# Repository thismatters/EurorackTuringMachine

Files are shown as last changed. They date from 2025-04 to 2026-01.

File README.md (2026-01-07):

# Turing Machine

The Turing Machine is a hugely popular module which produces random sequences of configurable length which can be held constant, or allowed to change slowly over time. Think of it like a sample-hold for sequences.

The circuit here is based on the [Music Thing Modular Turing Machine](https://github.com/TomWhitwell/TuringMachine) with some minor tweaks. The changes I've made are thus:
* Added polarity protection so that a backward power header doesn't fry anything (twin series schotty diodes: BAT54SL),
* Full surface mount design on a single PCB,
* Simpler input power filtering,
* Expanded length choices to include 7, 9, 11, and 13 (in addition to the default 2, 3, 4, 5, 6, 8, 12, and 16).
* Schmitt trigger with hysteresis on clock input to handle input signals which aren't perfectly smooth (alleviating the tendancy of the Music Thing Modular circuit to double-clock)

This module should be a drop-in replacement for the Musing Thing Modular version with the same width and same basic panel layout. I've altered it somewhat to fit with the aesthetic and practices of my DIY build, however the pinouts for expansion modules adhere exactly to the original. This repo inherits the same license as the original Turing Machine: [CC-BY-SA](https://creativecommons.org/licenses/by-sa/3.0/)

The KiCAD project here uses the library/footprints [found in my companion repo](https://github.com/thismatters/EurorackKiCAD).

Note resistors R1 and R2 have been removed. You will not find them in the schematic or BOM.

## Width

10hp

## Inputs

Jacks:
- Clock (required input) -- Max clock rate: 1300Hz; higher frequencies will cause bit smearing.
- CV for setting "Change" rate

Knobs:
- Change rate
- Sequence length (12 position switch)
- Scale

Write switch for setting the current bit high or low.

## Outputs

Jacks:
- CV output of of sequence
- Whitenoise
- Pulse whenever the current bit is high

LEDs:
- 8x for the current binary representation of the output tone
- 1x for the pulse
- 1x for the clock input

## Vendors

There are part numbers in the [BOM](turing-machine.csv) for many of the parts (not for basic passives though) at the following vendors:

* [Mouser](https://www.mouser.com): Needs no introduction. Get your ICs from here (or [digikey](https://www.digikey.com)).
* [Tayda Electronics](https://www.taydaelectronics.com/): Good supplier for passive components; audio jacks, and potentiometers. Their audio jacks are slightly smaller than the thonkiconn from thonk.
* [Love My Switches](https://lovemyswitches.com/): Has [really good knobs](https://lovemyswitches.com/anodized-aluminum-knob-the-lo-fi-1-4-smooth-shaft-12-5mm-od/) to go on those potentiometers!
* [OSHPark](https://oshpark.com/): Fast and (relatively) cheap PCB manufacturer. ~[V1 board works great!](https://oshpark.com/shared_projects/wF94N3Eb)~ There is a problem with the randomness and change circuitry. Needs a new version.

## Changelog

### V1

* [x] Fixed pinout for DAC0800 which is different for SOIC than PDIP
* [x] Write switch rotated 180deg
* [x] Filters between shift registers removed (max clock rate confirmed at around 1330Hz (E6))
* [x] Schmitt trigger supplements op-amp in gate input stage
* [x] Flipped trimmer and added hole to front panel so that trimming can happen _in-situ_, added note to PCB about how the trimmer should be oriented.

### V1a

* [x] Corrected C12 to have value of 1nF
* [x] Added test points for:
  * LOOP_CTRL'
  * RAND'
* [x] Investigated noise interference
  * When several LEDs are lit the noise level drops dramatically
  * clipping the LEDS from the prototype PCB alleviated the problem.
  * It seems produent to run the LEDS from the buffer outputs (which drive the expanders), and to drive the buffers from an isolated power circuit.
* [x] tested the V1 circuit driving LEDs from expander to see if secondary power circuit is necessary
  * it is. Driving the LEDs via the buffer still brings the +12V rail from 11.45V to 11.15V
* [x] Tested if ferrite bead in place of 10ohm resistor for power conditioning corrects noise interference issue (seems to work fine)
* [x] Updated power circuit to use ferrite bead (81-BLM21SP700BH1D) instead of resistor to more closely match original design

#### V1 -> V1a refit
* Change capacitor C12 value to 1nF.
* Use ferrite bead in place of resistors R1 and R2. A suitable part with an matching footprint is available from Mouser.com: part number 81-BLM21SP700BH1D.

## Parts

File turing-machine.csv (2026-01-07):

# | Reference | Qty | Value | Footprint | DNP | Vendor | PartNum
1 | C1, C2 | 2 | 22u 50V | Capacitor_THT:CP_Radial_D5.0mm_P2.50mm
2 | C3, C4, C11, C13, C19, C20, C21, C22, C23, C24, C25 | 11 | 100n | Capacitor_SMD:C_0805_2012Metric
3 | C5 | 1 | 10n | Capacitor_SMD:C_0805_2012Metric
4 | C6, C9, C12 | 3 | 1n | Capacitor_SMD:C_0805_2012Metric
5 | C7, C8, C10 | 3 | 470n box | Capacitor_THT:C_Rect_L7.2mm_W4.5mm_P5.00mm_FKS2_FKP2_MKS2_MKP2
6 | D1, D2 | 2 | BAT54S | Package_TO_SOT_SMD:SOT-23 |  | Mouser | 863-BAT54SLT1G
7 | D3, D14 | 2 | 1N4148 | Diode_SMD:D_SOD-323_HandSoldering
8 | D4, D5, D6, D7, D8, D9, D10, D11, D12, D13 | 10 | LED_GREEN | LED_THT:LED_D3.0mm
9 | FB1, FB2 | 2 | 70 Ohm | Inductor_SMD:L_0805_2012Metric |  | Mouser | 81-BLM21SP700BH1D
10 | J1 | 1 | Conn_02x05_Odd_Even | Eurorack:PinHeader_2x05_P2.54mm_Vertical |  | Tayda | A-2939
11 | J2 | 1 | cv | Eurorack:AudioJack2_Tayda_A-2566 |  | Tayda | A-2566
12 | J3 | 1 | clock | Eurorack:AudioJack2_Tayda_A-2566 |  | Tayda | A-2566
13 | J4 | 1 | out | Eurorack:AudioJack2_Tayda_A-2566 |  | Tayda | A-2566
14 | J5 | 1 | noise | Eurorack:AudioJack2_Tayda_A-2566 |  | Tayda | A-2566
15 | J6, J7 | 2 | Conn_02x08_Odd_Even | Eurorack:PinHeader_2x08_P2.54mm_Vertical |  | Tayda | A-2956
16 | J8 | 1 | pulse | Eurorack:AudioJack2_Tayda_A-2566 |  | Tayda | A-2566
17 | Q1 | 1 | BC547 | Package_TO_SOT_THT:TO-92_Inline_Wide |  | Mouser | 637-BC547C
18 | Q2 | 1 | BCM847 | Package_SO:TSOP-6_1.65x3.05mm_P0.95mm |  | Mouser | 771-BCM847DS135
19 | R3, R4, R10, R18, R25, R26, R27, R34 | 8 | 10K | Resistor_SMD:R_0805_2012Metric
20 | R5, R7, R11, R17, R21, R29 | 6 | 100K | Resistor_SMD:R_0805_2012Metric
21 | R6 | 1 | 51K | Resistor_SMD:R_0805_2012Metric
22 | R8 | 1 | 8.2K | Resistor_SMD:R_0805_2012Metric
23 | R9 | 1 | 470 | Resistor_SMD:R_0805_2012Metric
24 | R12 | 1 | 3.9K | Resistor_SMD:R_0805_2012Metric
25 | R13 | 1 | 5.1K | Resistor_SMD:R_0805_2012Metric
26 | R14 | 1 | 3.3K | Resistor_SMD:R_0805_2012Metric
27 | R15, R16 | 2 | 1.6K | Resistor_SMD:R_0805_2012Metric
28 | R19, R32 | 2 | 470K | Resistor_SMD:R_0805_2012Metric
29 | R20, R22, R24 | 3 | 1K | Resistor_SMD:R_0805_2012Metric
30 | R23, R33 | 2 | 2.2K | Resistor_SMD:R_0805_2012Metric
31 | R28 | 1 | 47K | Resistor_SMD:R_0805_2012Metric
32 | R30 | 1 | 68K | Resistor_SMD:R_0805_2012Metric
33 | R31 | 1 | 15K | Resistor_SMD:R_0805_2012Metric
34 | RN1 | 1 | 2.2K | Resistor_THT:R_Array_SIP9 |  | Mouser | 652-4609X-1LF-2.2K
35 | RV1, RV2 | 2 | B50K | Eurorack:Potentiometer_RV16AF-41-15R1
36 | RV3 | 1 | 5K | Potentiometer_THT:Potentiometer_Bourns_3296W_Vertical
37 | SW1 | 1 | SW_Rotary12 | Eurorack:Switch_Rotary_NKK_MRK_112 |  | Mouser | 633-MRK112-BA
38 | SW2 | 1 | SW_SPDT_MSM | Eurorack:Switch_SPDT_1M_Solder_Lug |  | Tayda | A-6099
39 | U1, U5, U14 | 3 | TL072 | Package_SO:SOIC-8_3.9x4.9mm_P1.27mm |  | Mouser | 595-TL072CDR
40 | U2 | 1 | DAC0800_SOIC | Package_SO:SOIC-16_3.9x9.9mm_P1.27mm |  | Mouser | 926-DAC0800LCMX/NOPB
41 | U3 | 1 | TL431DBZ | Package_TO_SOT_SMD:SOT-23 |  | Mouser | 595-TL431BCDBZTG4
42 | U4 | 1 | 4016 | Package_SO:TSSOP-14_4.4x5mm_P0.65mm |  | Mouser | 595-CD4016BPWR
43 | U6, U7 | 2 | 4015 | Package_SO:TSSOP-16_4.4x5mm_P0.65mm |  | Mouser | 595-CD4015BPWR
44 | U8, U11 | 2 | L78L09_SOT89 | Package_TO_SOT_SMD:SOT-89-3 |  | Mouser | 511-L78L09ACU
45 | U9, U10 | 2 | 4050 | Package_SO:TSSOP-16_4.4x5mm_P0.65mm |  | Mouser | 595-CD4050BPWR
46 | U12, U13 | 2 | 4081 | Package_SO:TSSOP-14_4.4x5mm_P0.65mm |  | Mouser | 595-CD4081BPWR

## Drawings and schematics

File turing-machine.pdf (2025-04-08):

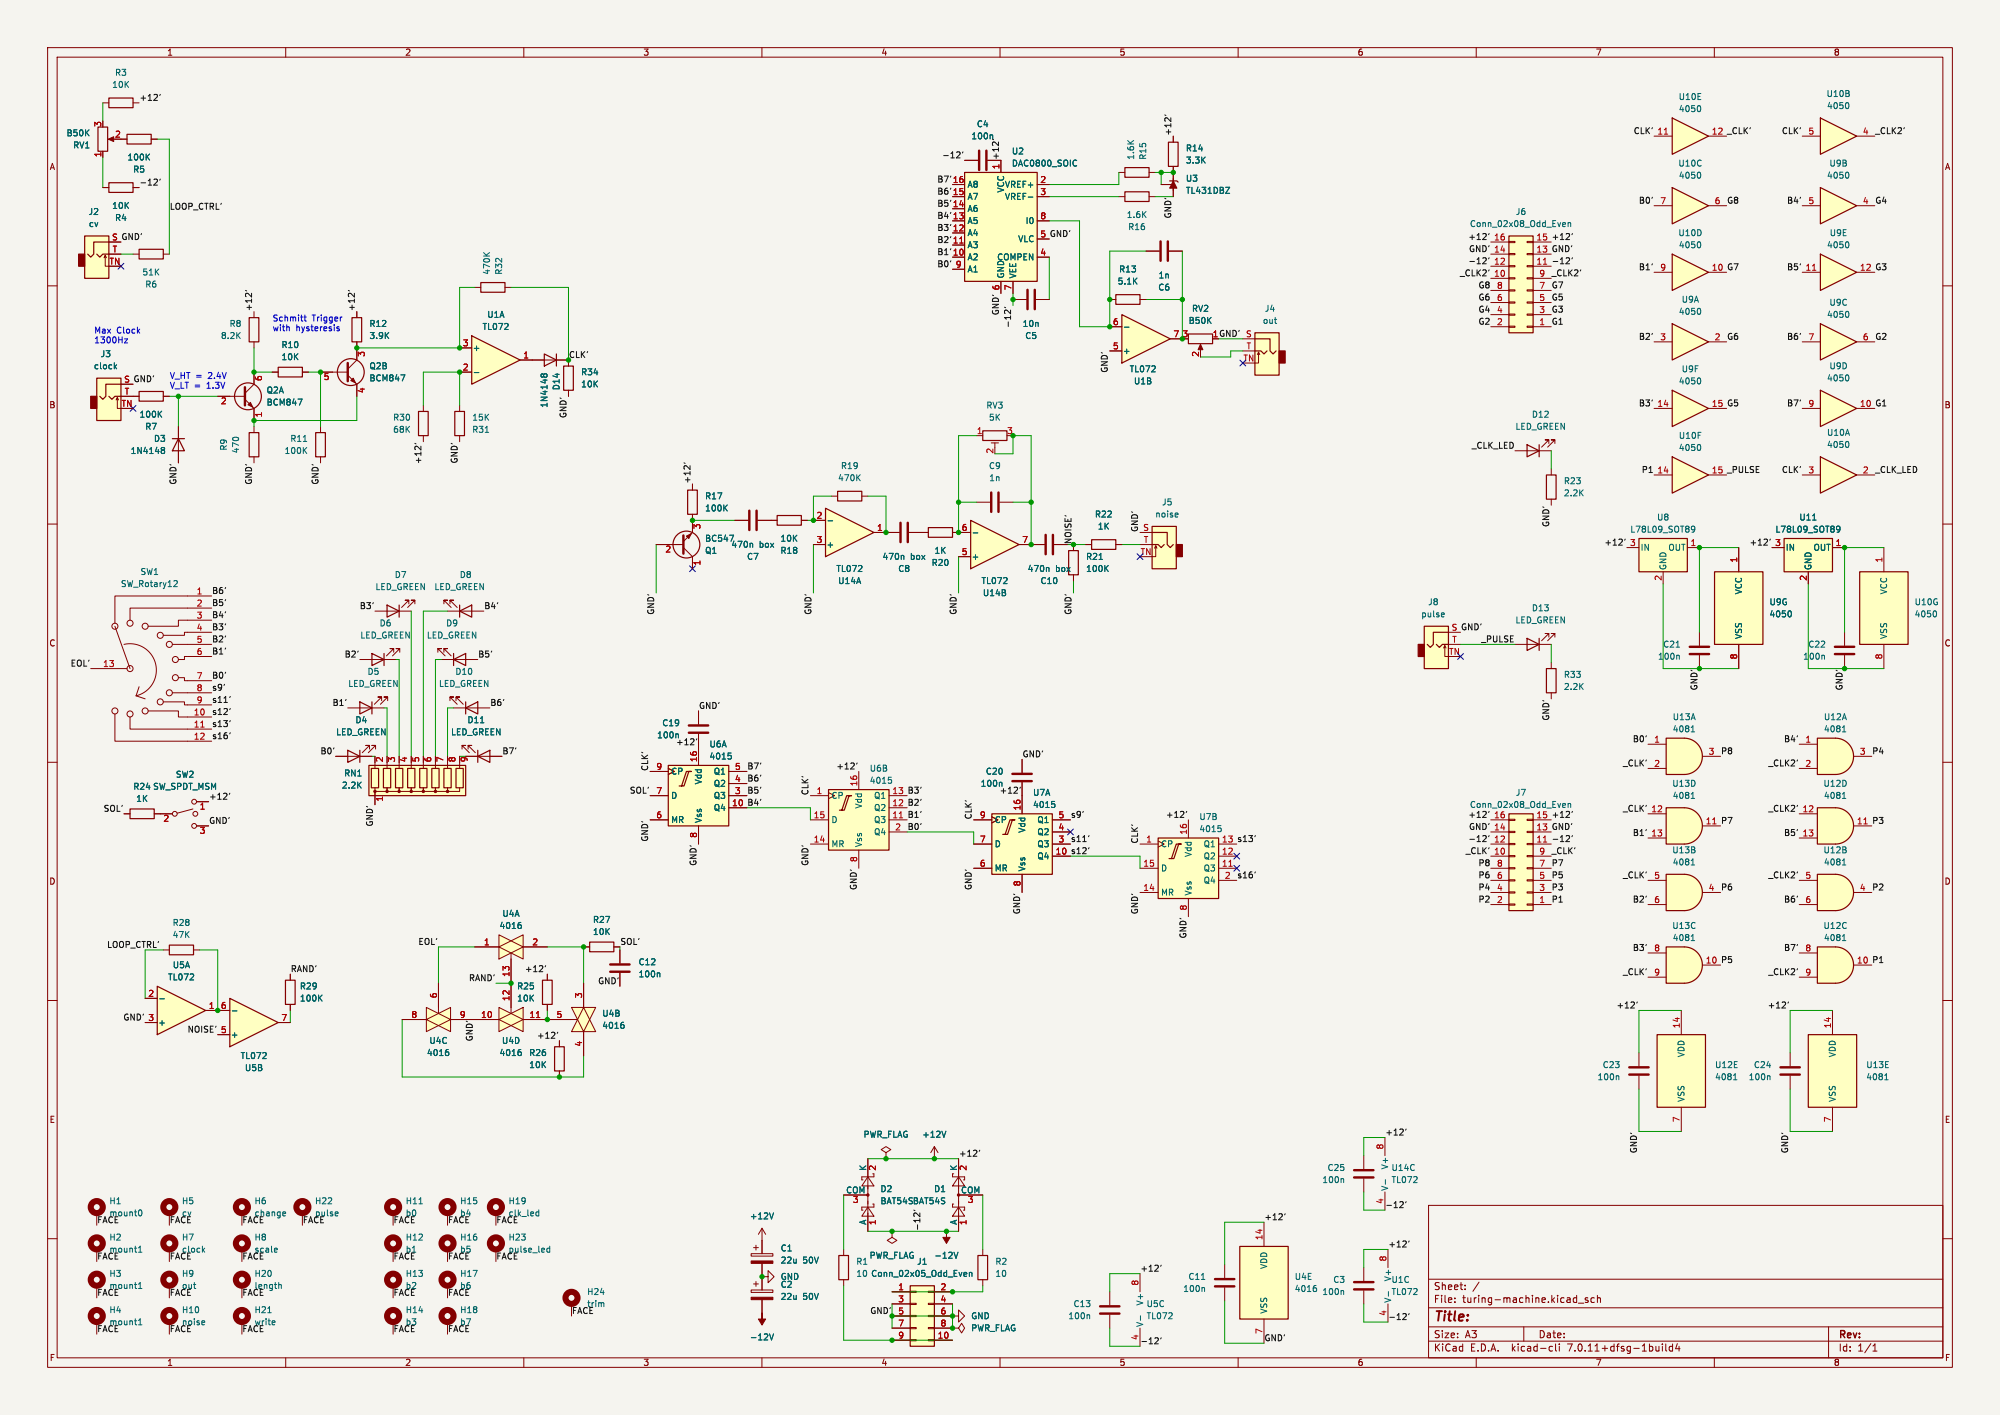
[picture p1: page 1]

1 A2 10 A3 11 A4 12 A5 13 A6 14 A7 15 A8 16 VREF+ 2 VREF- 3 COMPEN 4 VLC 5 GND

Id: 1/1 Title: File: turing-machine.kicad_sch Sheet: / +12V H8

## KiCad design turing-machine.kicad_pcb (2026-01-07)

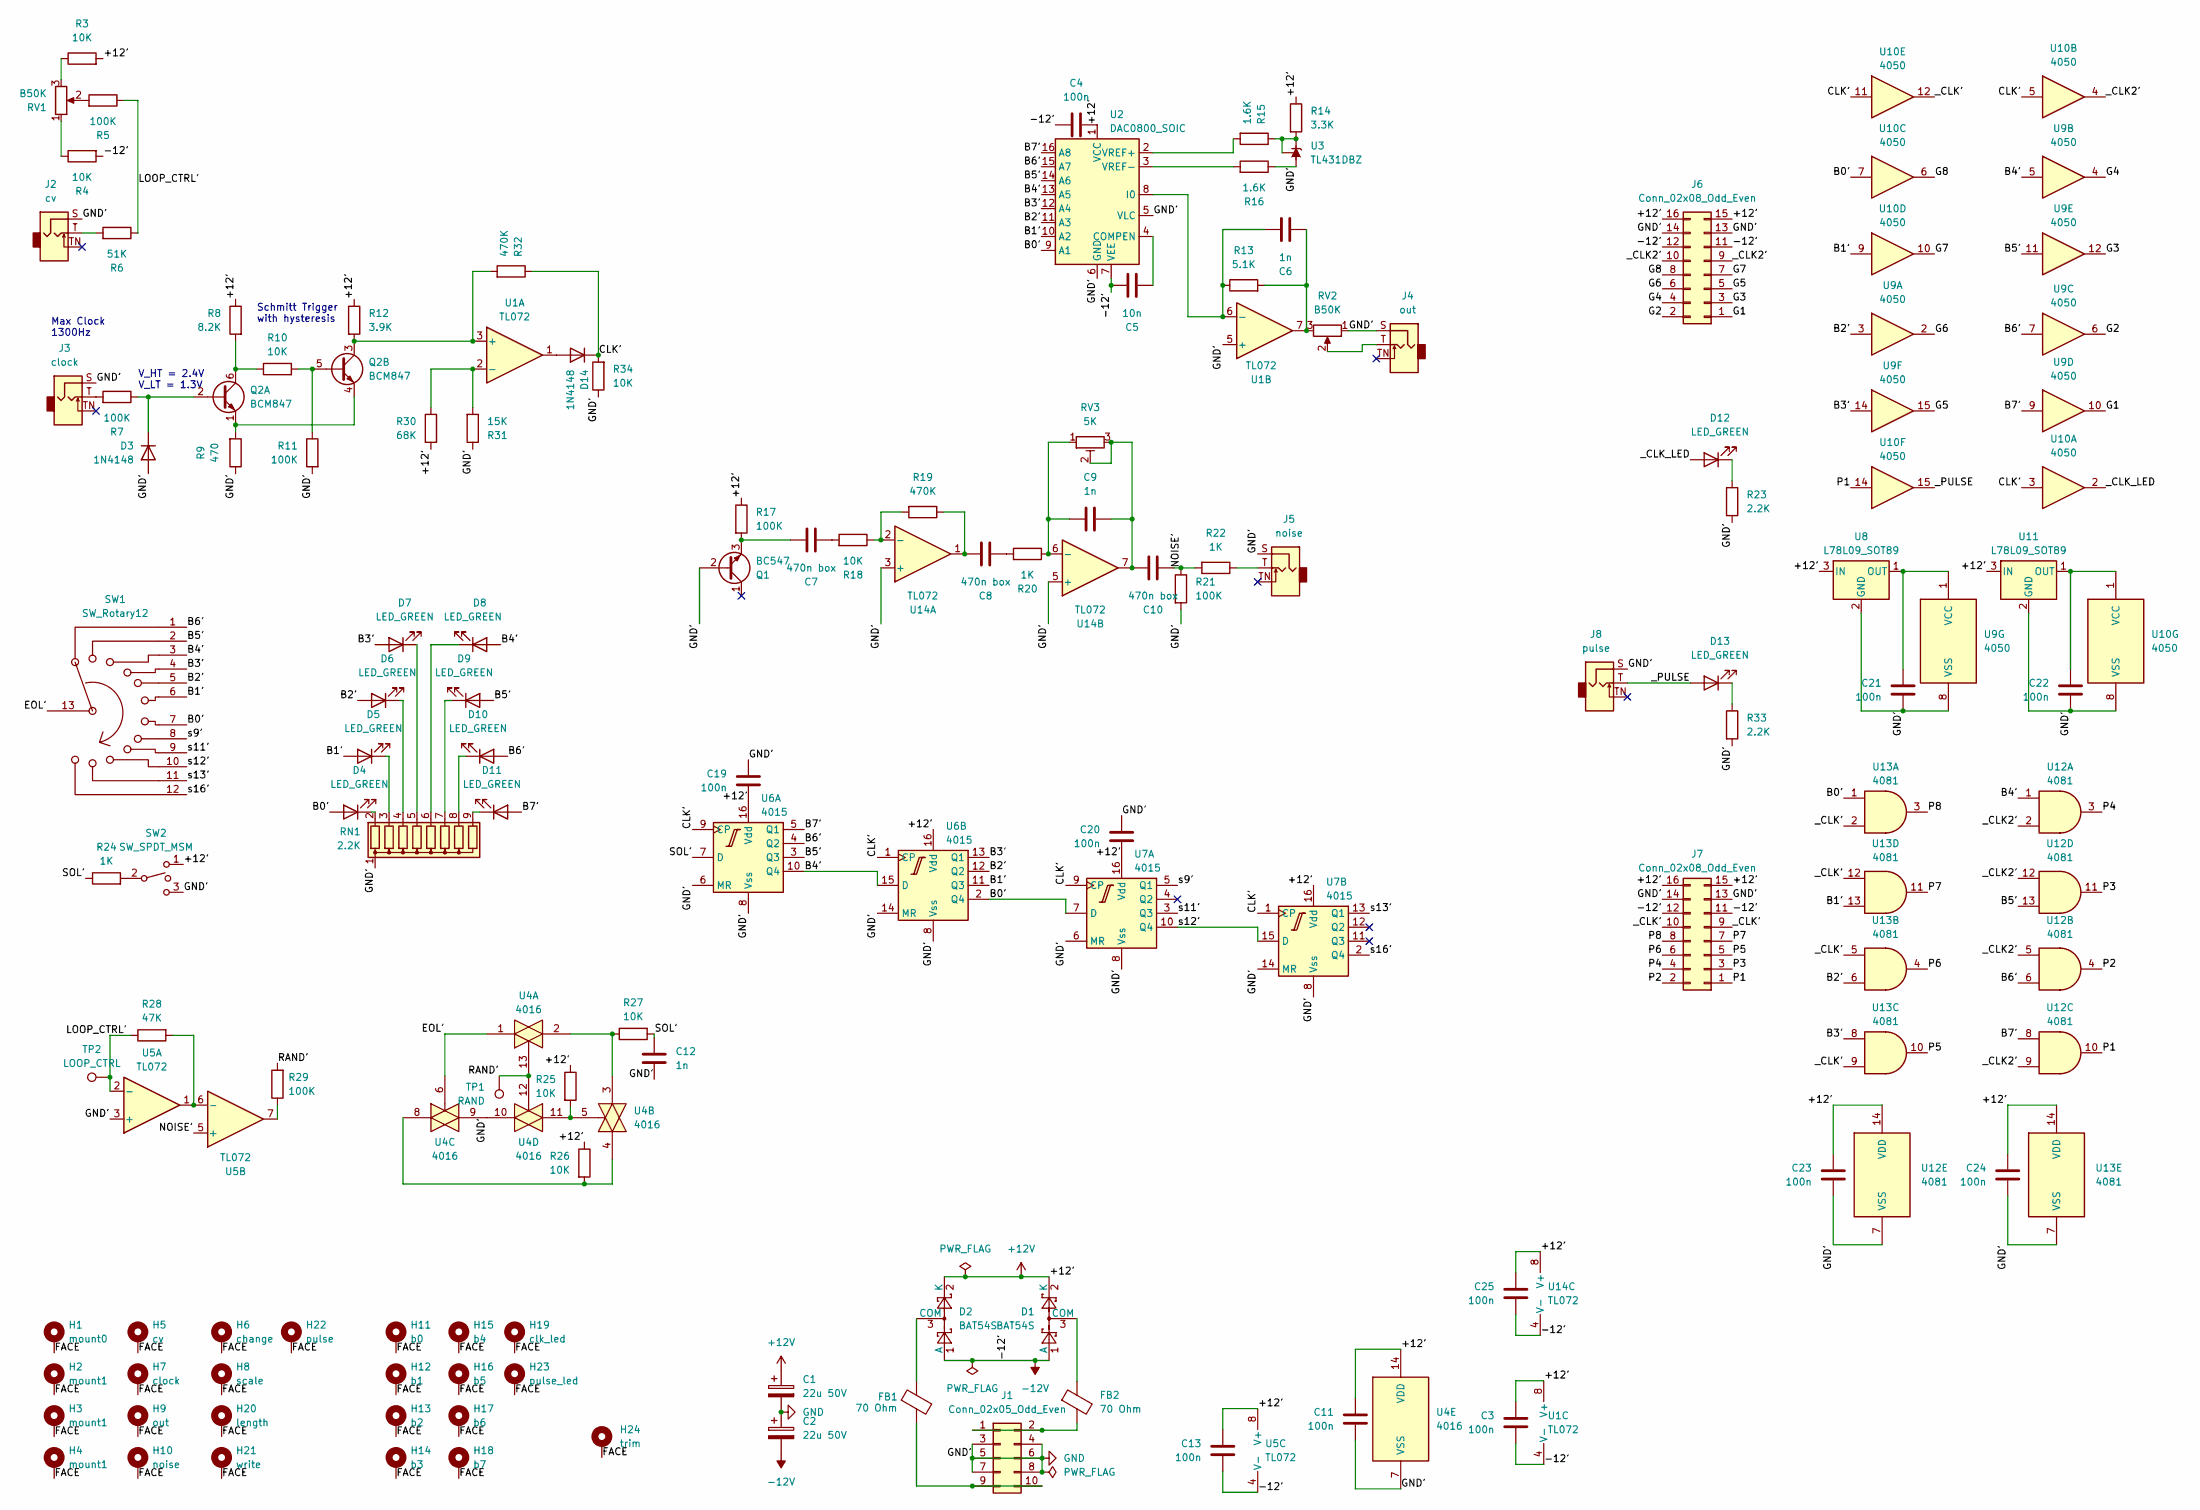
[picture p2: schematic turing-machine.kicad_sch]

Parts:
C1, C2: 22u 50V; CP_Radial_D5.0mm_P2.50mm
C3, C4, C11, C13, C19, C20, C21, C22, C23, C24, C25: 100n; C_0805_2012Metric
C5: 10n; C_0805_2012Metric
C6, C9, C12: 1n; C_0805_2012Metric
C7, C8, C10: 470n box; C_Rect_L7.2mm_W4.5mm_P5.00mm_FKS2_FKP2_MKS2_MKP2
D1, D2: BAT54S; SOT-23; PartNum 863-BAT54SLT1G
D3, D14: 1N4148; D_SOD-323_HandSoldering
D4, D5, D6, D7, D8, D9, D10, D11, D12, D13: LED_GREEN; LED_D3.0mm
FB1, FB2: 70 Ohm; L_0805_2012Metric; PartNum 81-BLM21SP700BH1D
H1: mount0; Mech-MountingHole
H2, H3, H4: mount1; Mech-MountingHole
H5: cv; Mech-AudioJack-Hole-Input-CV
H6: change; Mech-Potentiometer-Hole_level_180deg
H7: clock; Mech-AudioJack-Hole-Input-Clock
H8: scale; Mech-Potentiometer-Hole_level
H9: out; Mech-AudioJack-Hole-Output-CV
H10: noise; Mech-AudioJack-Hole-Output
H11: b0; Mech-LED-Hole-3mm
H12: b1; Mech-LED-Hole-3mm
H13: b2; Mech-LED-Hole-3mm
H14: b3; Mech-LED-Hole-3mm
H15: b4; Mech-LED-Hole-3mm
H16: b5; Mech-LED-Hole-3mm
H17: b6; Mech-LED-Hole-3mm
H18: b7; Mech-LED-Hole-3mm
H19: clk_led; Mech-LED-Hole-3mm
H20: length; Mech-MRK-Hole
H21: write; Mech-1M_Switch-Hole
H22: pulse; Mech-AudioJack-Hole-Output-Gate
H23: pulse_led; Mech-LED-Hole-3mm
H24: trim; Mech-LED-Hole-3mm
J1: Conn_02x05_Odd_Even; PinHeader_2x05_P2.54mm_Vertical; PartNum A-2939
J2: cv; AudioJack2_Tayda_A-2566; PartNum A-2566
J3: clock; AudioJack2_Tayda_A-2566; PartNum A-2566
J4: out; AudioJack2_Tayda_A-2566; PartNum A-2566
J5: noise; AudioJack2_Tayda_A-2566; PartNum A-2566
J6, J7: Conn_02x08_Odd_Even; PinHeader_2x08_P2.54mm_Vertical; PartNum A-2956
J8: pulse; AudioJack2_Tayda_A-2566; PartNum A-2566
Q1: BC547; TO-92_Inline_Wide; PartNum 637-BC547C
Q2: BCM847; TSOP-6_1.65x3.05mm_P0.95mm; PartNum 771-BCM847DS135
R3, R4, R10, R18, R25, R26, R27, R34: 10K; R_0805_2012Metric
R5, R7, R11, R17, R21, R29: 100K; R_0805_2012Metric
R6: 51K; R_0805_2012Metric
R8: 8.2K; R_0805_2012Metric
R9: 470; R_0805_2012Metric
R12: 3.9K; R_0805_2012Metric
R13: 5.1K; R_0805_2012Metric
R14: 3.3K; R_0805_2012Metric
R15, R16: 1.6K; R_0805_2012Metric
R19, R32: 470K; R_0805_2012Metric
R20, R22, R24: 1K; R_0805_2012Metric
R23, R33: 2.2K; R_0805_2012Metric
R28: 47K; R_0805_2012Metric
R30: 68K; R_0805_2012Metric
R31: 15K; R_0805_2012Metric
RN1: 2.2K; R_Array_SIP9; PartNum 652-4609X-1LF-2.2K
RV1, RV2: B50K; Potentiometer_RV16AF-41-15R1
RV3: 5K; Potentiometer_Bourns_3296W_Vertical
SW1: SW_Rotary12; Switch_Rotary_NKK_MRK_112; PartNum 633-MRK112-BA
SW2: SW_SPDT_MSM; Switch_SPDT_1M_Solder_Lug; PartNum A-6099
TP1: RAND; TestPoint_Plated_Hole_D2.0mm
TP2: LOOP_CTRL; TestPoint_Plated_Hole_D2.0mm
U1, U5, U14: TL072; SOIC-8_3.9x4.9mm_P1.27mm; PartNum 595-TL072CDR
U2: DAC0800_SOIC; SOIC-16_3.9x9.9mm_P1.27mm; PartNum 926-DAC0800LCMX/NOPB
U3: TL431DBZ; SOT-23; PartNum 595-TL431BCDBZTG4
U4: 4016; TSSOP-14_4.4x5mm_P0.65mm; PartNum 595-CD4016BPWR
U6, U7: 4015; TSSOP-16_4.4x5mm_P0.65mm; PartNum 595-CD4015BPWR
U8, U11: L78L09_SOT89; SOT-89-3; PartNum 511-L78L09ACU
U9, U10: 4050; TSSOP-16_4.4x5mm_P0.65mm; PartNum 595-CD4050BPWR
U12, U13: 4081; TSSOP-14_4.4x5mm_P0.65mm; PartNum 595-CD4081BPWR

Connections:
+12V: C1.1, C3.1, C4.2, C11.1, C13.1, C19.2, C20.2, C23.1, C24.1, C25.1, D1.2 (K), D2.2 (K), J6.15, J6.16, J7.15, J7.16, R3.2, R8.1, R12.1, R14.1, R17.1, R25.1, R26.1, R30.2, SW2.1, U1.8 (V+), U2.1 (VCC), U4.14 (VDD), U5.8 (V+), U6.16 (Vdd), U7.16 (Vdd), U8.3 (IN), U11.3 (IN), U12.14 (VDD), U13.14 (VDD), U14.8 (V+)
-12V: C2.2, C3.2, C4.1, C5.1, C13.2, C25.2, D1.1 (A), D2.1 (A), J6.11, J6.12, J7.11, J7.12, R4.2, U1.4 (V-), U2.7 (VEE), U5.4 (V-), U14.4 (V-)
/B0': D4.2 (A), SW1.7, U2.9 (A1), U6.2 (Q4), U7.7 (D), U10.7, U13.1
/B1': D5.2 (A), SW1.6, U2.10 (A2), U6.11 (Q3), U10.9, U13.13
/B2': D6.2 (A), SW1.5, U2.11 (A3), U6.12 (Q2), U9.3, U13.6
/B3': D7.2 (A), SW1.4, U2.12 (A4), U6.13 (Q1), U9.14, U13.8
/B4': D8.2 (A), SW1.3, U2.13 (A5), U6.10 (Q4), U6.15 (D), U9.5, U12.1
/B5': D9.2 (A), SW1.2, U2.14 (A6), U6.3 (Q3), U9.11, U12.13
/B6': D10.2 (A), SW1.1, U2.15 (A7), U6.4 (Q2), U9.7, U12.6
/B7': D11.2 (A), U2.16 (A8), U6.5 (Q1), U9.9, U12.8
/CLK': D14.1 (K), R32.1, R34.2, U6.1 (CP), U6.9 (CP), U7.1 (CP), U7.9 (CP), U10.3, U10.5, U10.11
/EOL': SW1.13, U4.1, U4.6
/FACE: H1.1, H2.1, H3.1, H4.1, H5.1, H6.1, H7.1, H8.1, H9.1, H10.1, H11.1, H12.1, H13.1, H14.1, H15.1, H16.1, H17.1, H18.1, H19.1, H20.1, H21.1, H22.1, H23.1, H24.1
/G1: J6.1, U9.10
/G2: J6.2, U9.6
/G3: J6.3, U9.12
/G4: J6.4, U9.4
/G5: J6.5, U9.15
/G6: J6.6, U9.2
/G7: J6.7, U10.10
/G8: J6.8, U10.6
/LOOP_CTRL': R5.1, R6.1, R28.1, TP2.1, U5.2 (-)
/NOISE': C10.2, R21.1, R22.2, U5.5 (+)
/P1: J7.1, U10.14, U12.10
/P2: J7.2, U12.4
/P3: J7.3, U12.11
/P4: J7.4, U12.3
/P5: J7.5, U13.10
/P6: J7.6, U13.4
/P7: J7.7, U13.11
/P8: J7.8, U13.3
/RAND': R29.2, TP1.1, U4.12, U4.13
/SOL': C12.1, R24.1, R27.2, U6.7 (D)
/_CLK2': J6.9, J6.10, U10.4, U12.2, U12.5, U12.9, U12.12
/_CLK': J7.9, J7.10, U10.12, U13.2, U13.5, U13.9, U13.12
/_CLK_LED: D12.2 (A), U10.2
/_PULSE: D13.2 (A), J8.T, U10.15
/s9': SW1.8, U7.5 (Q1)
/s11': SW1.9, U7.3 (Q3)
/s12': SW1.10, U7.10 (Q4), U7.15 (D)
/s13': SW1.11, U7.13 (Q1)
/s16': SW1.12, U7.2 (Q4)
GND: C1.2, C2.1, C11.2, C12.2, C19.1, C20.1, C21.2, C22.2, C23.2, C24.2, D3.2 (A), J1.3, J1.4, J1.5, J1.6, J1.7, J1.8, J2.S, J3.S, J4.S, J5.S, J6.13, J6.14, J7.13, J7.14, J8.S, Q1.2 (B), R9.1, R11.2, R16.1, R21.2, R23.2, R31.1, R33.2, R34.1, RN1.1 (common), RV2.1, SW2.3, U1.5 (+), U2.5 (VLC), U2.6 (GND), U3.3 (A), U4.7 (VSS), U4.9, U4.10, U5.3 (+), U6.6 (MR), U6.8 (Vss), U6.14 (MR), U7.6 (MR), U7.8 (Vss), U7.14 (MR), U8.2 (GND), U9.8 (VSS), U10.8 (VSS), U11.2 (GND), U12.7 (VSS), U13.7 (VSS), U14.3 (+), U14.5 (+)
unnamed: C6.2, R13.2, RV2.3, U1.7
unnamed: C7.2, R18.2
unnamed: C8.1, R19.1, U14.1
unnamed: C8.2, R20.2
unnamed: C9.2, C10.1, RV3.2, RV3.3, U14.7
unnamed: D1.3 (COM), FB2.1
unnamed: D2.3 (COM), FB1.1
unnamed: D3.1 (K), Q2.2 (B1), R7.1
unnamed: D4.1 (K), RN1.2 (R1)
unnamed: D5.1 (K), RN1.3 (R2)
unnamed: D6.1 (K), RN1.4 (R3)
unnamed: D7.1 (K), RN1.5 (R4)
unnamed: D8.1 (K), RN1.6 (R5)
unnamed: D9.1 (K), RN1.7 (R6)
unnamed: D10.1 (K), RN1.8 (R7)
unnamed: D11.1 (K), RN1.9 (R8)
unnamed: D12.1 (K), R23.1
unnamed: D13.1 (K), R33.1
unnamed: D14.2 (A), U1.1
unnamed: FB2.2, J1.1, J1.2
unnamed: FB1.2, J1.9, J1.10
unnamed: J2.T, R6.2
unnamed: J3.T, R7.2
unnamed: J4.T, RV2.2
unnamed: J5.T, R22.1
unnamed: C7.1, Q1.3 (E), R17.2
unnamed: Q2.6 (C1), R8.2, R10.1
unnamed: Q2.1 (E1), Q2.4 (E2), R9.2
unnamed: Q2.5 (B2), R10.2, R11.1
unnamed: Q2.3 (C2), R12.2, R32.2, U1.3 (+)
unnamed: R3.1, RV1.3
unnamed: R4.1, RV1.1
unnamed: R5.2, RV1.2
unnamed: R24.2, SW2.2
unnamed: R25.2, U4.5, U4.11
unnamed: R26.2, U4.4, U4.8
unnamed: R27.1, U4.2, U4.3
unnamed: R29.1, U5.7
unnamed: R30.1, R31.2, U1.2 (-)
unnamed: C6.1, R13.1, U1.6 (-), U2.8 (I0)
unnamed: C5.2, U2.4 (COMPEN)
unnamed: R15.2, U2.2 (VREF+)
unnamed: R16.2, U2.3 (VREF-)
unnamed: R14.2, R15.1, U3.1 (K), U3.2 (REF)
unnamed: R28.2, U5.1, U5.6 (-)
unnamed: C21.1, U8.1 (OUT), U9.1 (VCC)
unnamed: C22.1, U10.1 (VCC), U11.1 (OUT)
unnamed: R18.1, R19.2, U14.2 (-)
unnamed: C9.1, R20.1, RV3.1, U14.6 (-)

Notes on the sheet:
Schmitt Trigger with hysteresis
Max Clock 1300Hz
V_HT = 2.4V V_LT = 1.3V

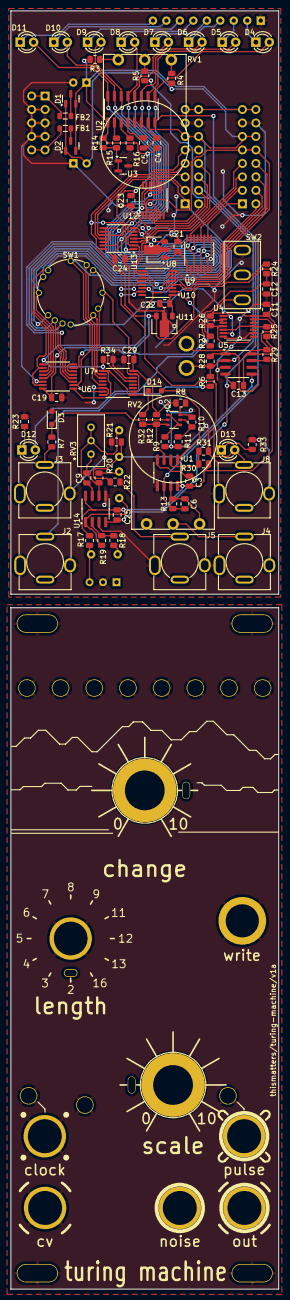
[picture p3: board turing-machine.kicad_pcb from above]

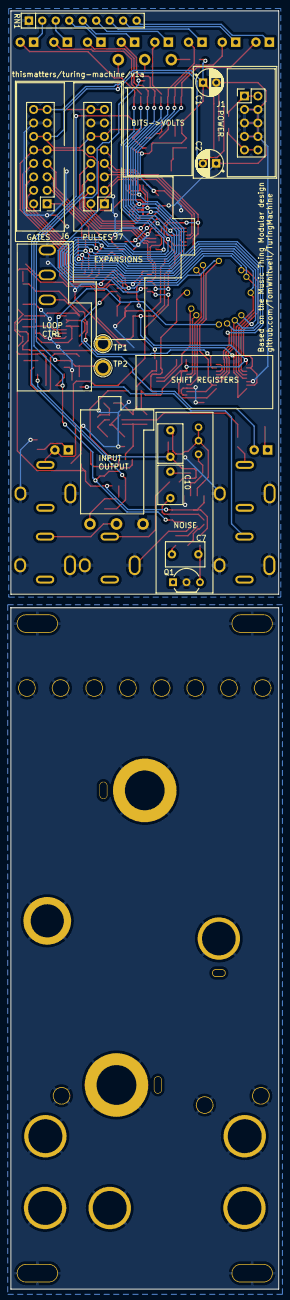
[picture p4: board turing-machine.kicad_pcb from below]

Board: 2 copper layers, 50.5 x 241.0 mm, 124 parts (12 on the bottom side), 92 nets.

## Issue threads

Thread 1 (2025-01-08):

Rotary switch alternative?

CoogLFish, 2025-01-08:
The rotary switch in the BOM is around 26€ at Mouser, Digikey and the likes, which is a bit steep. Do you know an alternative manufacturer with the same footprint?

thismatters, 2025-01-11:
Hi! You're right that the NKK MR-K112 switch is quite expensive, like an order of magnitude more expensive than any other part I use! Some relief can be found on Alibaba where this switch sells for closer to $8, but that's still quite expensive and the quality may be ...dubious.

Having gotten a number of these switches from Mouser I can say that the quality of them is superb. They have a very satisfying detent, and despite the very small knob they are pleasant to operate; in my mind this mitigates the pricetag to some degree. Including this switch and the PCB (ignoring that you must buy a lot of 3 PCBs from the manufacturer I use) the module has a unit cost of $62.09, just over half the price of a Turing Machine kit.

A big downside (other than price) is that their shaft is a non-standard size, sourcing knobs is troublesome so I use the ones that are sold along with the unit (MR-K112-BA).

The original Turing Machine uses an 8 position switch which is much more affordable. That said, I'm using this 12 position switch in some other modules (e.g. ClockDiv2) and I though it would be cool for the Turing Machine to be able to do some prime number poly-rhythms.

Unfortunately, having spent several hours on Mouser and Digikey looking for alternatives, I have yet to see any which satisfy these requirements:
* Small package suitable to use in 1U modules (cannot exceed 22.5mm diameter, although the smaller the better for the sake of overall module size),
* Suitably short package to mount alongside jacks and potentiometers (cannot exceed 11mm height, installed),
* 12 position switch (the 2 pole 6 throw is also a variant that will be used in future modules).

Most of the 12 position switches I see are these [huge plastic monstrosities](https://www.taydaelectronics.com/rotary-switch-1-pole-12-position-alpha-sr2611f.html) which are not fitted for PCB mounting, and wouldn't fit comfortably in a Winnebago! Switches of that variety are right out given the design criteria and aesthetic I've chosen for my build.

If you come across a suitable part that I've overlooked I would be happy to revise this design to include it! I'm not committed to the exact footprint of the MR-K112, if another, cheaper form factor satisfies the requirements I would like to adopt it before I send this module for its first prototyping run.

CoogLFish, 2025-01-13:
Thank you for your comprehensive answer. I'll keep looking into into it.

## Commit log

2025-01-01 PCB layout complete
    [turing-machine.csv, turing-machine.kicad_pcb, turing-machine.kicad_sch]
2025-01-01 fix: getting all parts sorted out
    [turing-machine.csv, turing-machine.kicad_pcb, turing-machine.kicad_sch]
2025-01-05 fix: available parts only
    [turing-machine.csv, turing-machine.kicad_pcb, turing-machine.kicad_sch]
2025-01-23 ready for v0 manu
    [turing-machine.csv, turing-machine.kicad_pcb, turing-machine.kicad_sch]
2025-04-08 ready for v1 manu
    [turing-machine.kicad_pcb, turing-machine.kicad_sch]
2025-04-08 now with updated bom
    [turing-machine.csv]
2026-01-01 adding results from troubleshooting
    [turing-machine.csv, turing-machine.kicad_pcb, turing-machine.kicad_sch]
2026-01-07 v1a board ready, refit of v1 board available
    [turing-machine.csv, turing-machine.kicad_pcb, turing-machine.kicad_sch]
